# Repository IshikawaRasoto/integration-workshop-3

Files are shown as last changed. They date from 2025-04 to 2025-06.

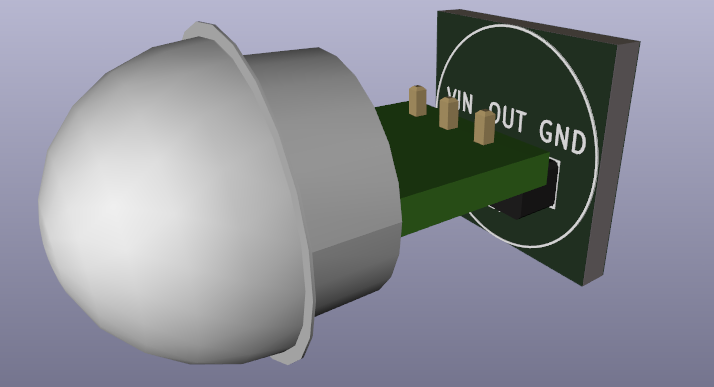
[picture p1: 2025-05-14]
electronics/kicad-5/documentation/am312_breakout/images/3d_view.png

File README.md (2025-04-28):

# Melody - Team #6

This repository contains all the development of project Melody for the course of Integration Workshop 3 in UTFPR-CT.

## Links 🔗

- [Project Overview](Melody.md) 🎵
- [Blog](Blog.md) :pencil2:
- [Schedule](https://docs.google.com/spreadsheets/d/16BKpbmt_EArwLnEZPB5oZgRN8s5iP5gV15BQ9Iq-7wM/edit?usp=sharing) :calendar:
- [Requirements](https://docs.google.com/spreadsheets/d/1uYC0gMrYfBv8li1KcnDvk5HJS1G1zU4XR2CenMT3GNY/edit?usp=sharing) ✔️
- [Risk Response Plans](https://docs.google.com/document/d/1Hm508SiW-laHHYEpOHIg4PhOxUlGecafFV3NObWFzSE/edit?usp=sharing)

## Members

- Rafael Rasoto 

- Nicolas Riuichi Oda 

- Augusto Rosa  

- Bruno Zenatti  

- Fernando Caetano  

- Rogério Slabiski Melo

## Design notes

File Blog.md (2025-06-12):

# Blog - Team #6

## Links 🔗

- [Project Review](./Melody.md) 🔍
  
- [Schedule](https://docs.google.com/spreadsheets/d/16BKpbmt_EArwLnEZPB5oZgRN8s5iP5gV15BQ9Iq-7wM/edit?usp=sharing) :calendar:
  
- [Requirements](https://docs.google.com/spreadsheets/d/1uYC0gMrYfBv8li1KcnDvk5HJS1G1zU4XR2CenMT3GNY/edit?usp=sharing) ✔️

- [Risk Analysis](./docs/ProjectRisks.md)

- [Risk Response Plans](https://docs.google.com/document/d/1Hm508SiW-laHHYEpOHIg4PhOxUlGecafFV3NObWFzSE/edit?usp=sharing)

- [Budget](./docs/Budget.md)
  
- [Software Diagramas](https://drive.google.com/drive/u/0/folders/1p14QvT_csh-KTkunY4fwNIppBQ_Pb9lO)

> [!NOTE]
> The more you scroll, older the posts will be.

## 11th week (06/06/2025 - 12/06/2025)

<a href="https://www.youtube.com/watch?v=N3duTqVcuXE">Link for Youtube Video</a>

> [!NOTE]
> The video is in portuguese because our project aims brazillians music teachers. However, there are English subtitles made by ourselves available on Youtube. Just enable them if you want :D

## 10th week (30/05/2025 - 05/06/2025)

https://github.com/user-attachments/assets/fdecbd82-0494-4a7e-a883-67b1e470544c

> [!NOTE]
> video doesn't work, here is the <a href="https://drive.google.com/file/d/1t6a54CX3tAcsUsGrWydN2q878OG4VS5w/view?usp=sharing">alternative link</a>
> or <a href="https://youtu.be/I3bCHIlh-NA"> another alternative link</a>

## 9th week (23/05/25 - 29/05/25)

Watch the video (https://youtu.be/XbjRi2Wo8Gw)

> [!NOTE]
> video doesn't work, here is the <a href="https://drive.google.com/file/d/1zL92fwCrnUkS4uXp7pSdOqfEj2-jlHWw/view?usp=sharing">alternative link</a>
> or <a href="https://youtu.be/XbjRi2Wo8Gw"> another alternative link</a>

### Weekly Progress Report

- **Worked Hours:** 41 hours  
- **Estimated Hours:** 57 hours 

#### Late Tasks:
- Implement gamified modes on the board
- Finish and Test electronics, on the universal board

**Total:** 10 hours

#### Advanced Tasks:
- Integrate configuration and mode selection via the web
- Assembly of the electronics in the mechanical system (Partial)
- Integrate software modules (Partial)

**Total:** 9 hours

### Balance of Hours:
- **-1 hours (Delayed)**

## 8th week (16/05/25 - 22/05/25)

Watch the video (https://youtu.be/CQ0k8XT7MOg)

> [!NOTE]
> video doesn't work, here is the <a href="https://drive.google.com/file/d/1eBVnDomfoXzMXdfsafBxS9mqTwlVErr4/view?usp=sharing">alternative link</a>
> or <a href="https://youtu.be/CQ0k8XT7MOg"> another alternative link</a>

### Weekly Progress Report

- **Worked Hours:** 50  
- **Estimated Hours:** 49  

#### Late Tasks:
- Acessibility Box adjusts
- PCB Test and Fine adjusts
- Plan note detection algorithm
- Communication between Raspberry and ESP
- Electronics integration 

**Total:** 12 hours

#### Advanced Tasks:
-  Creation Mode Logic
-  Gamified Modes Logic
-  Configuration and Mode selection via Web

**Total:** 10 hours

### Balance of Hours:
- **-2 hours (Delayed)**

### [Software Diagrams](https://drive.google.com/drive/u/0/folders/1p14QvT_csh-KTkunY4fwNIppBQ_Pb9lO)

## 7th week (10/05/25 - 15/05/25)

Watch the video (https://youtu.be/vphRbDHo6h4)

> [!NOTE]
> video doesn't work, here is the <a href="https://drive.google.com/file/d/1HU00oeIiyC617RvUnKEH0RWAW4GVyMLu/view?usp=sharing">alternative link</a>
> or <a href="https://youtu.be/vphRbDHo6h4"> another alternative link</a>

### Weekly Progress Report

- **Worked Hours:** 39  
- **Estimated Hours:** 51  

#### Late Tasks:
- Painting the table (musical sheet)  
- Universal board  
- Assembly of camera support and accessibility box  
- Technical drawing of the camera support  
**Total:** 24 hours

#### Advanced Tasks:
- Web interface  
- Implementation of the API between the Raspberry Pi and the web interface  
- Software flowchart  
**Total:** 15 hours

### Balance of Hours:
- **-9 hours (Delayed)**

### Considerations:
The machine responsible for laser cutting was inoperable this week due to a lack of distilled water. As a result, the camera support and accessibility box could not be completed. Painting the table is not a time-sensitive task, so it was postponed.

## 6th week (02/05/25 - 09/05/25)

https://github.com/user-attachments/assets/304e5314-0793-4925-b9ff-8a7de1e51dcb

> [!NOTE]
> video doesn't work, here is the <a href="https://drive.google.com/file/d/11PbM4jwNMG-VzaX_eZv_z7f3hip6sJxV/view?usp=drive_link">alternative link</a>

## 5th week (25/04/25 - 01/05/25)

https://drive.google.com/file/d/171ncvKebdySRcL43Z6NbSYb8b0LnE4rA/view?usp=sharing

> [!NOTE]
> video doesn't work, here is the <a href="https://drive.google.com/file/d/171ncvKebdySRcL43Z6NbSYb8b0LnE4rA/view?usp=sharing">alternative link</a>

This week we worked on modeling the mechanical part of Melody.

---

## 4th week (17/04/25 - 24/04/25)

https://github.com/user-attachments/assets/338b94e7-9b9c-4a17-a485-34453e6bfb96

> [!NOTE]
> If the video doesn't work, here is the <a href="https://drive.google.com/file/d/1DF5MuI8baSHS0etINNkh2YdKUNlma0PU/view?usp=sharing">alternative link</a>

This Week we worked on the planning of the project. As such, we:

- Defined the functional and non-functional requirements
- Defined the schedule of the project
- Propose the mitigation tasks for the top 10 priority risks of the project.

### Weekly Video

## 3rd week (10/04/25 - 16/04/25)

After selecting **Melody – MElodic LOgic for DYnamic learning** as our official project last week, our focus shifted towards planning. The main goals of the week included:

- Defining functional and non-functional requirements
- Structuring our project schedule
- Designing basic system diagrams
- Estimating a preliminary budget (B.O.M.)

---

### Weekly Video

https://github.com/user-attachments/assets/63315553-2686-44ac-ae38-a748cd99c074

- Project overview
- Requirements (hardware/software)
- Preliminary budget
- Task division and timeline

---

### Initial Schedule

Our starter project timeline here:  

📌 [Schedule Spreadsheet](https://docs.google.com/spreadsheets/d/1K51avpQig4mYJVM0eIMD89h_2f8xq5VL/edit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)

---

### Requirements

Detailed functional and non-functional requirements are available:  

📄 [Requirements Document](https://github.com/IshikawaRasoto/integration-workshop-3/blob/main/docs/Requirements.md)

---

### Risk Analysis

We started risk analysis this week to get a feedback from the professors:

:bomb: [Risk Analysis Preview ](https://docs.google.com/document/d/1Hm508SiW-laHHYEpOHIg4PhOxUlGecafFV3NObWFzSE/edit?usp=sharing)

---

### Bill of Materials (B.O.M.)

| Item | Price |
| --- | --- |
| USB Cam | R$ 100,00 |
| Raspberry Pi 4 B | R$ 300,00 |
| 3D Printing (2 PLA rolls) | R$ 150,00 |
| Plywood for board and camera mount | R$ 70,00 - R$ 200,00 |
| Simple Speaker | R$ 50,00 |
| 4x Servo Motor SG90 | R$ 50,00 |
| ESP32 | R$ 30,00 |
| Motor Vibracall | R$ 10,00 |
| 35x LEDs | R$ 20,00 |
| General Electronic Components | R$ 15,00 - R$ 75,00 |
| 2x Light Sources | R$ 30,00 |
| **Total** | **R$ 825,00 - R$ 1.015,00** |

---

### Weekly Meetings Recap

-Mon (14/04/25): Enhance the electronic part of the project, define the requirements of the project.

-Tue (15/04/25): Plan the project schedule, delegate responsabilities to the project members.

-Wen (16/04/25): Project diagrams, B.O.M,

---

## 2nd Week (03/04/25 - 09/04/25)

### Video of the week

https://github.com/user-attachments/assets/f6084483-0107-445c-9c83-dd5aefe4133e

> [!NOTE]
> If the video above doesn't work, here is the <a href="https://drive.google.com/file/d/1AGoXJWrNMAOkMldZtp4LrVlzvFSptPVR/view?usp=drive_link">link</a>

The feedback from the first week was the approval to continue develop our proposal A and also bring another idea. For this week, the team is supposed to deliver in more details both ideas.

### Week Proposals

- <a href="https://github.com/IshikawaRasoto/integration-workshop-3/blob/main/Melody.md">A. Melody</a> 🎵

- <a href="https://github.com/IshikawaRasoto/integration-workshop-3/blob/main/BajaValidation.md">B. Baja Validation </a> 🚙

## 1st Week (27/03/25 - 02/04/25)

As requested by the professors, the video below has a 10 minutes presentation about 3 proposals of projects to be developed during the course.

https://github.com/user-attachments/assets/d645352b-6435-41c7-a563-1140d3d22fad

> [!NOTE]
> If the video doens't work, here's the <a href="https://drive.google.com/file/d/1P5hyUBTmhP22Z2IB0QPu1I9AHRTu6y-r/view?usp=sharing">video link</a>

### A. Musicalization Project

The musicalization project has the objective to engage children in learning musical theory. Our proposal looks formward to the development of a table in which children can position pieces in a board which will represent the musical notes. The user will be able to control tempo, choose the instrument sound of which the system will play the notes, will have 2 or 3 octaves that can be chosen by the user. 

### B. Commercial Bafometer and Personal Bafometer

Project B seeks to solve a problema common in most of young adults lives. How to know if you are already sober after a session of drinking. Looking to solve this problem, our team is proposing the development of a system which will tell if a person is able to drive, and from this device, we'll be able to predict when a person will be able to drive by his metabolism, and also develop a system for places which sell drinks to ensure that, if someone is driving, he will only be able to take his car keys if he is sober and suited to drive.

### C. Parking Efficiency

Project C has the objective to solve a problem common in parking lots of concerts and shopping malls in events. The idea is to develop a smart system that will control the flow of vehicles entering and exiting the shopping mall in the most efficient way.

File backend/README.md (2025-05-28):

# Rodando o Servidor
- Crie o virtual enviroment
- Instale os pacotes do requirements.txt
- Na root do projeto (:~/integration-workshop-3$):
```
python3 main.py
```

# Documentação: Diretórios `core/` e `modes/`

Esta documentação detalha os componentes dos diretórios `core/` e `modes/` do projeto Melody, com foco no propósito de cada módulo e nas tarefas pendentes (TODOs).

---

### Diretório `core/`

O diretório `core/` contém os módulos centrais que formam a base da funcionalidade do projeto Melody.

#### 1. `core/hardware.py`

* **Propósito**: Este módulo é responsável por interagir com os componentes de hardware do projeto. Atualmente, ele define funções para controlar LEDs.
* **Funcionalidades**:
    * `turnOnLed(indexLed, color="GREEN")`: Acende um LED específico com uma cor definida (o padrão é verde).
    * `turnOffLed(indexLed)`: Apaga um LED específico.
* **🔴 TODOs/Pontos Pendentes**:
    * Implementar botões para chamar as respectivas funções de configuração (`set_volume`, `set_tempo`, `play/stop`).
    * Realmente acender e apagar os respectivos leds
    * Implementar um botão de emergência que reseta tudo.
    * Desenvolver a comunicação com o ESP32.
    * Implementar o controle do servo motor.
    * Implementar o controle do motor de vibração (vibracall).

---

#### 2. `core/noteDetection.py`

* **Propósito**: Este módulo é projetado para lidar com a detecção de notas musicais, presumivelmente através de uma câmera ou outro sensor.
* **Funcionalidades**:
    * `NoteDetection` (classe):
        * `__init__(self)`: Inicializa o detector, configurando `notes_detected` como `None` e `running` como `True`.
        * `detect_note_loop(self)`: Contém o loop principal para a detecção de notas.
        * `get_notes_detected(self)`: Retorna as notas detectadas.
        * `stop_note_detection_thread(self)`: Para a thread de detecção de notas.
* **🔴 TODOs/Pontos Pendentes**:
    * Implementar toda a lógica para detectar as notas dentro de `detect_note_loop`. A variável `self.notes_detected` é crucial e deve ser atualizada por esta lógica.

---

#### 3. `core/session.py`

* **Propósito**: Este módulo é **crucial** para o gerenciamento do estado global da aplicação. Ele mantém informações sobre o volume, tempo, estado de reprodução, página atual da interface, melodia selecionada, nota atual, status de acessibilidade e o índice da nota atual na melodia. Ele centraliza o estado para que diferentes partes do sistema (API, modos de operação) possam acessá-lo e modificá-lo de forma consistente. As funções `set_*` atualizam o estado e, em alguns casos, imprimem o novo valor no console para depuração. A função `as_dict()` é usada para transmitir o estado atual, provavelmente para a interface do usuário via WebSockets.
* **Funcionalidades**:
    * `PlayerState` (dataclass): Define a estrutura para armazenar o estado da sessão.
        * `volume`: Volume atual (0-100%).
        * `tempo`: Andamento atual (BPM).
        * `playing`: Booleano indicando se a música está tocando.
        * `page`: String que representa a página/estado atual da interface.
        * `melody`: Nome ou ID da melodia selecionada.
        * `note`: Nota atual dentro da melodia.
        * `accessibility`: Booleano indicando se o modo de acessibilidade está ativo.
        * `note_index`: Índice da nota atual na melodia.
    * `set_volume(value: int)`: Define o volume, limitado entre 0 e 100.
    * `set_tempo(bpm: int)`: Define o tempo, limitado entre 60 e 120 BPM.
    * `start_playback()`: Define `state.playing` como `True`.
    * `stop_playback()`: Define `state.playing` como `False`.
    * `select_melody(name: str)`: Seleciona uma melodia e define a nota inicial.
    * `set_page(name: str)`: Define a página/estado atual da interface.
    * `set_note(note: str)`: Define a nota atual.
    * `set_note_index(idx: int)`: Define o índice da nota atual.
    * `set_accessibility(flag: bool)`: Ativa/desativa o modo de acessibilidade.
    * `play_current_melody_note()`: Toca a nota atual da melodia selecionada, considerando sua duração.
    * `as_dict()`: Retorna o estado atual como um dicionário.
* **🔴 TODOs/Pontos Pendentes**:
    * Em `set_volume(value: int)`: Implementar a lógica para de fato **AUMENTAR O VOLUME NO ALTO-FALANTE**.
    * Em `play_current_melody_note()`: Adicionar a lógica para mais duas melodias além de "Ovelha Preta".

---

#### 4. `core/soundPlaying.py`

* **Propósito**: Este módulo é dedicado à geração e reprodução de sons de notas musicais. Ele usa `numpy` para gerar as ondas sonoras e `sounddevice` para reproduzi-las.
* **Funcionalidades**:
    * `sample_rate`: Taxa de amostragem para o áudio (44100 Hz).
    * `envelope(t, attack, decay, sustain_level, release)`: Define o envelope ADSR (Attack, Decay, Sustain, Release) para a nota, moldando sua amplitude ao longo do tempo.
    * `synthesize_note(frequency, duration)`: Gera a forma de onda para uma nota com uma determinada frequência e duração, aplicando o envelope.
    * `play_note_async(note, duration)`: Função assíncrona para tocar uma nota. Busca a frequência da nota no dicionário `note_freqs` (de `core.utils`), sintetiza a onda sonora (usando `asyncio.to_thread` para não bloquear o loop de eventos) e a reproduz usando `sounddevice`.
    * `run_sequence()`: Uma função de exemplo para tocar uma sequência de notas (escala de Dó).
* **🔴 TODOs/Pontos Pendentes**: Nenhum TODO explícito marcado no código, mas a funcionalidade depende das frequências de notas e melodias definidas em `core/utils.py`.

---

#### 5. `core/utils.py`

* **Propósito**: Este módulo serve como um utilitário para armazenar dados e constantes usados em outras partes do projeto, como definições de melodias e frequências de notas.
* **Funcionalidades**:
    * `OVELHA_PRETA`: Uma lista de tuplas representando as notas e suas durações para a melodia "Ovelha Preta".
    * `note_freqs`: Um dicionário mapeando nomes de notas (e seus acidentes como sustenido '#' ou bemol 'b') para suas frequências em Hertz.
* **🔴 TODOs/Pontos Pendentes**:
    * Adicionar o *hardcode* de mais melodias (sequência de notas com duração).
    * Completar o *hardcode* de notas, com suas frequências, etc. (embora `note_freqs` já pareça bastante completo).
    * Implementar o *hardcode* do mapeamento de notas (cor -> nota), que seria usado pela detecção de notas baseada em cores.

---

### Diretório `modes/`

O diretório `modes/` contém módulos que definem os diferentes modos de operação da aplicação Melody. Cada modo geralmente tem uma função `run_mode()` que é executada quando esse modo está ativo. O `ModeManager` em `backend/main.py` controla a transição entre esses modos com base no valor de `session.state.page`.

#### 1. `modes/creation.py`

* **Propósito**: Define o comportamento do "Modo de Criação". Neste modo, o sistema toca uma sequência de notas em loop, acendendo LEDs correspondentes a cada tempo/coluna no tabuleiro.
* **Funcionalidades**:
    * `run_mode()`: Loop principal do modo.
        * Verifica se `session.state.playing` é `True`.
        * Calcula o `columnIndex` (0-15) baseado nos `beats`.
        * Apaga o LED da coluna anterior e acende o LED da coluna atual.
        * Toca a nota correspondente à coluna atual da melodia `notes_and_durations`.
        * Incrementa `beats` e espera um tempo baseado no `session.state.tempo`.
    * `get_empty_board()`: Retorna uma representação de um tabuleiro vazio.
    * `get_duration_value(duration_string)`: Converte a string de duração ("quarter", "half", "whole") para um valor numérico.
* **🔴 TODOs/Pontos Pendentes**:
    * A variável `notes_and_durations` está atualmente usando `OVELHA_PRETA` como *mock*. Precisa ser atualizada para usar as notas realmente detectadas (presumivelmente do `noteDetection.py`) ou uma melodia que o usuário está criando.
    * No `run_mode()`, ao tocar a nota, deve usar a lista atualizada de notas, não uma fixa.

---

#### 2. `modes/hear.py`

* **Propósito**: Define o "Modo Escute a Nota". A intenção é que o sistema toque uma nota de uma melodia pré-carregada, e o usuário tente identificar e posicionar a nota correspondente no tabuleiro. O sistema então daria feedback.
* **Funcionalidades**:
    * `run_mode()`: Loop principal do modo.
        * Espera que `session.state.playing` seja `True` e que uma melodia (`session.state.melody`) esteja selecionada.
        * Contém placeholders para a lógica principal.
* **🔴 TODOs/Pontos Pendentes**:
    * Tocar a nota atual da melodia.
    * Esperar que o usuário posicione a nota correspondente.
    * Usar `noteDetection` para verificar se a nota posicionada corresponde à tocada.
    * Acender LED verde se correto e avançar o índice da nota.
    * Acender LED vermelho se incorreto.
    * Acender LED amarelo se nada for detectado.

---

#### 3. `modes/identify.py`

* **Propósito**: Define o "Modo Identifique a Nota". Neste modo, o sistema indica uma nota (presumivelmente mostrando-a na interface ou de outra forma visual), e o usuário deve posicioná-la no tabuleiro. O sistema verifica a correção.
* **Funcionalidades**:
    * `run_mode()`: Loop principal do modo.
        * Espera que `session.state.playing` seja `True` e que uma melodia (`session.state.melody`) esteja selecionada.
        * Contém placeholders para a lógica principal.
* **🔴 TODOs/Pontos Pendentes**:
    * Ler a nota atual da melodia usando `note_index`.
    * Usar `noteDetection` para ler a nota posicionada pelo usuário.
    * Comparar a nota detectada com a nota esperada.
    * Acender LED verde se correto e avançar o índice.
    * Acender LED vermelho se incorreto.
    * Acender LED amarelo se nada for detectado.

---

#### 4. `modes/idle.py`

* **Propósito**: Define o modo "Idle" ou "Home". Este é o estado padrão ou inicial da aplicação. Ele reseta a seleção de melodia e para a reprodução.
* **Funcionalidades**:
    * `run_mode()`:
        * Seleciona `None` para a melodia (`session.select_melody(None)`).
        * Para a reprodução (`session.stop_playback()`).
        * Entra em um loop enquanto `session.state.page` for "home".
        * Verifica se `session.state.accessibility` está ativo para executar a lógica correspondente.
* **🔴 TODOs/Pontos Pendentes**:
    * Se `session.state.accessibility` for `True`, implementar a lógica de comunicação com o ESP32 ("Turn on ESP32 Communication").

---

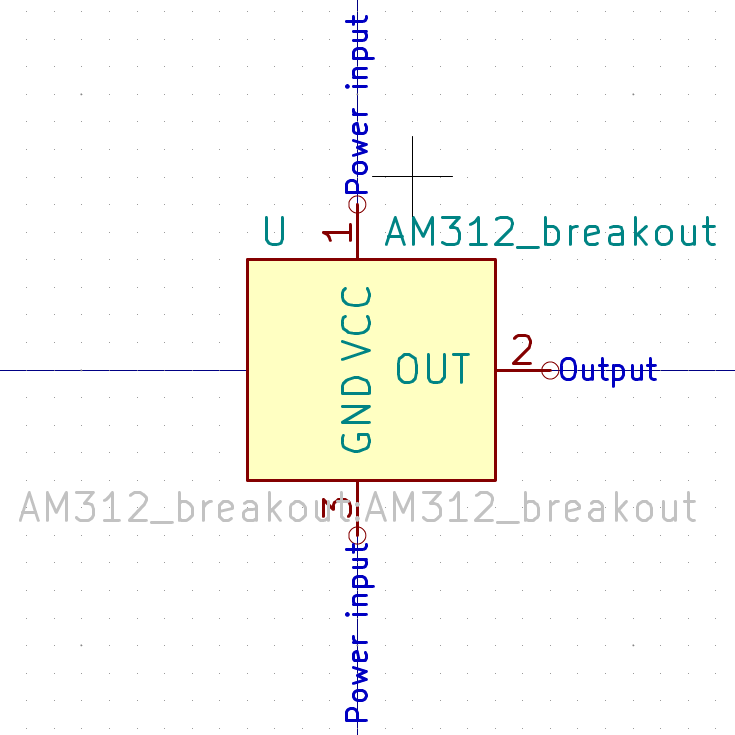
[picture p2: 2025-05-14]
electronics/kicad-5/documentation/aht10_breakout/images/symbol.png

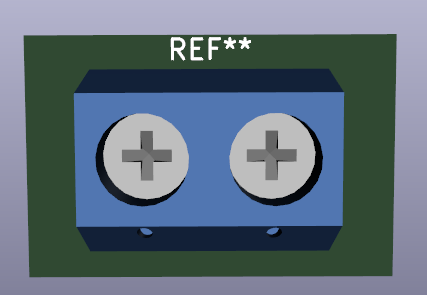
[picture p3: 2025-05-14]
electronics/kicad-5/documentation/kf301_5.0/images/3d_top.png

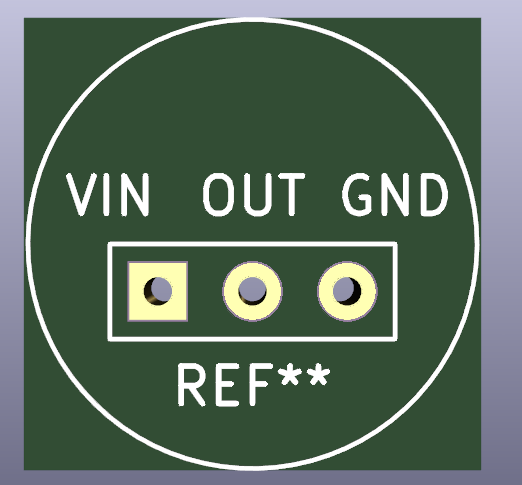
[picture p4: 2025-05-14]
electronics/kicad-5/documentation/am312_breakout/images/3d_silk.png

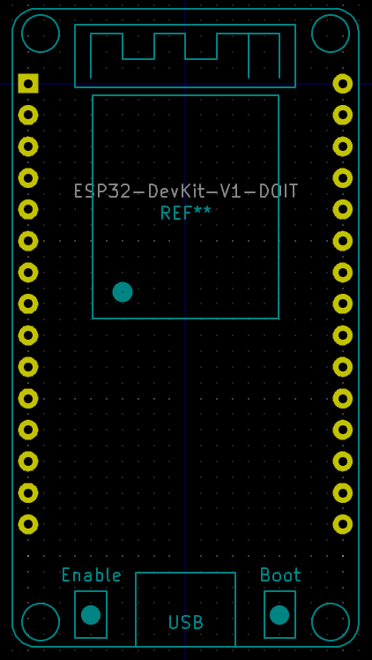
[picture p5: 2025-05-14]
electronics/kicad-5/documentation/esp32_devkit_v1_doit/images/footprint.png

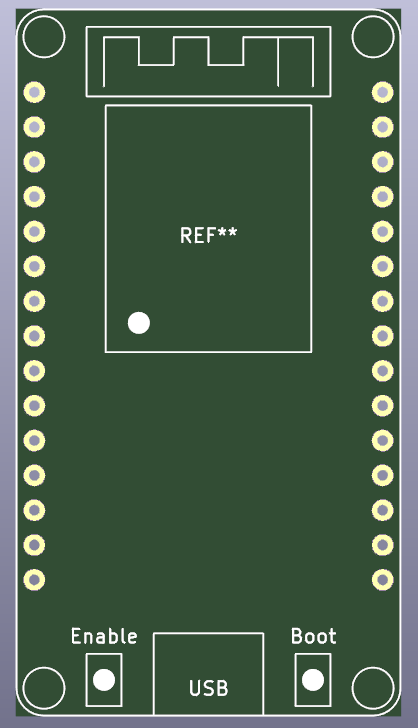
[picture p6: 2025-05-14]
electronics/kicad-5/documentation/esp32_devkit_v1_doit/images/3d_silk.png

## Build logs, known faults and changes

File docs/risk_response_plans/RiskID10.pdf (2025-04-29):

## Risk Response Plan Form

### Project: Melody

1st Step: Risk Identification
Name of the Risk:
Webcam wobbling

ID N°
10
Risk Description:
The webcam may shake or shift slightly due to an unstable or poorly mounted support structure, causing recognition errors or misalignment of visual input.

2nd Step: Risk Evaluation
Impact: 1(Very Low) 2(Low) 3(Average) X4(High) 5(Very High)

Explanation:
Camera wobbling can reduce image stability, leading to occasional recognition errors.

Probability:1(Very Low) X2(Low) 3(Average) 4(High) 5(Very High)

Explanation:
The camera mount is a physical structure that may initially be built from lightweight or imprecise materials

3rd Step: Risk Response Plan
Task, Who will do it, When it will be done! Strategies and Tasks that should be performed in order to reduce the “Impact”/“Probability” of this risk: Prevention Tasks:
Pin the webcam stand on the board. Include rubber pads or anti-slip elements at the base.

Mitigation Tasks:
Change the exposure time of the webcam to reduce motion blur.

Transfer* (use in last case, avoid if possible):

Acceptance Tasks (avoid at all costs!):

(* At Integration Workshop 3, it would not be possible to “transfer” the Risk outside of the team!)
Re-evaluated Impact (1~5): | 3 | Re-evaluated Probability (1-5): | 2
Elaborated by: Bruno | Date: 23/04/2025

Form based on Gasnier, 2000 (IMAN Editor), adjusted by Wille(UTFPR), translated to English by Fabro(UTFPR).

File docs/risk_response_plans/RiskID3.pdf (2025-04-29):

## Risk Response Plan Form

### Project: Melody

1st Step: Risk Identification
Name of the Risk:
Physical structure does not fit or align correctly (holes, webcam stand)

ID N°
3
Risk Description:
Misalignment or incorrect dimensions in the physical components (e.g., note holes, LED placement, webcam mount).

2nd Step: Risk Evaluation
Impact: 1(Very Low) 2(Low) X3(Average) 4(High) 5(Very High)

Explanation:
If the physical structure does not fit or align correctly, it may get harder to implement all requirements.

Probability:1(Very Low) 2(Low) 3(Average) X4(High) 5(Very High)

Explanation:
The team members are not used to projecting mechanical structures, it’s likely that the projects have some mistakes.

3rd Step: Risk Response Plan
Task, Who will do it, When it will be done! Strategies and Tasks that should be performed in order to reduce the “Impact”/“Probability” of this risk: Prevention Tasks:
Double-check all measurements and spacing (Double the time).
Mark drilling points carefully and test positioning before committing to permanent modifications. Involve more than one team member in reviewing and validating the design.

Mitigation Tasks:
Adjust or re-drill components if misalignment is minor and can be corrected.
Keep extra materials on hand for fast rework if needed, buy extra before working.

Transfer* (use in last case, avoid if possible):

Acceptance Tasks (avoid at all costs!):

(* At Integration Workshop 3, it would not be possible to “transfer” the Risk outside of the team!)
Re-evaluated Impact (1~5): 3 | Re-evaluated Probability (1-5): 2
Elaborated by: Bruno | Date: 23/04/2025

Form based on Gasnier, 2000 (IMAN Editor), adjusted by Wille(UTFPR), translated to English by Fabro(UTFPR).

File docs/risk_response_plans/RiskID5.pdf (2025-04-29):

## Risk Response Plan Form

### Project: Melody

1st Step: Risk Identification
Name of the Risk:
Problems with Raspberry Pi performance (lag or overheating)

ID N°
5
Risk Description:
If the board doesn’t accomplish what is expected

2nd Step: Risk Evaluation
Impact: 1(Very Low) 2(Low) X3(Average) 4(High) 5(Very High)

Explanation:
This might impact on the child’s interest about the project, the system might experience delays in processing or audio playback. It would just reduce responsiveness or cause minor interruptions.

Probability:1(Very Low) 2(Low) X3(Average) 4(High) 5(Very High)

Explanation:
The raspberry pi chosen for the project is quite good, but it is still a possibility.

3rd Step: Risk Response Plan
Task, Who will do it, When it will be done! Strategies and Tasks that should be performed in order to reduce the “Impact”/“Probability” of this risk: Prevention Tasks:
Limit camera frame rate and resolution and monitoring system resource usage during development.

Mitigation Tasks:
Include a reboot/restart mechanism in case the system becomes unresponsive.

Transfer* (use in last case, avoid if possible):

Acceptance Tasks (avoid at all costs!):

(* At Integration Workshop 3, it would not be possible to “transfer” the Risk outside of the team!)
Re-evaluated Impact (1~5): 2 | Re-evaluated Probability (1-5):2
Elaborated by: Bruno | Date: 23/04/2025

Form based on Gasnier, 2000 (IMAN Editor), adjusted by Wille(UTFPR), translated to English by Fabro(UTFPR).

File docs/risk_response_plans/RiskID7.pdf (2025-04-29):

## Risk Response Plan Form

### Project: Melody

1st Step: Risk Identification
Name of the Risk:
Power supply is unstable or insufficient

ID N°
7
Risk Description:
If the power supply doesn’t supply enough power to the system or the power source has fluctuations

2nd Step: Risk Evaluation
Impact: 1(Very Low) 2(Low) X 3(Average) 4(High) 5(Very High)

Explanation:
There might not be enough power to actuate the motors and power the raspberry and ESP32, the motors might end up causing instabilities in the power for the electronics

Probability: 1(Very Low) 2(Low) X 3(Average) 4(High) 5(Very High)

Explanation:
The power load calculated might no be enough to the whole system, the effect of the motors in the system might be more than expected

3rd Step: Risk Response Plan
| Task, Who will do it, When it will be done!
Strategies and Tasks that should be performed in order to reduce the “Impact”/“Probability” of this risk: Prevention Tasks:
Use a power supply with enough power to power the system at max load.

Mitigation Tasks:
Separate the power supply in two circuits, one for the raspberry and ESP32 and other for the power electronics.

Transfer* (use in last case, avoid if possible):

Acceptance Tasks (avoid at all costs!):

(* At Integration Workshop 3, it would not be possible to “transfer” the Risk outside of the team!)
Re-evaluated Impact (1~5): 2 | Re-evaluated Probability (1-5): 2
Elaborated by: Fernando | Date: 23/04/2025

Form based on Gasnier, 2000 (IMAN Editor), adjusted by Wille(UTFPR), translated to English by Fabro(UTFPR).

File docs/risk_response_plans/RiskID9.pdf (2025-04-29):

## Risk Response Plan Form

### Project: Melody

1st Step: Risk Identification
Name of the Risk:
Hardware component burns out

ID N°
9
Risk Description:
Hardware components like the might burn out from misuse

2nd Step: Risk Evaluation
Impact: 1(Very Low) 2(Low) 3(Average) X 4(High) 5(Very High)

Explanation:
Some components like the LEDs or the motors might impact the functionality but the rest of the system would still be functional. Failure of the raspberry would impact the whole system.

Probability: 1(Very Low) X 2(Low) 3(Average) 4(High) 5(Very High)

Explanation:
The members of the team have experience handling the components used in the system, unlikely to happen.

3rd Step: Risk Response Plan
| Task, Who will do it, When it will be done!
Strategies and Tasks that should be performed in order to reduce the “Impact”/“Probability” of this risk: Prevention Tasks:
Test the connections and subcircuits before assembling the whole circuit.

Mitigation Tasks:
Having a spare Raspberry 3B, 4 Servo motors, a vibration motor and a ESP32.

Transfer* (use in last case, avoid if possible):

Acceptance Tasks (avoid at all costs!):

(* At Integration Workshop 3, it would not be possible to “transfer” the Risk outside of the team!)
Re-evaluated Impact (1~5): 2 | Re-evaluated Probability (1-5): 2
Elaborated by: Fernando | Date: 23/04/2025

Form based on Gasnier, 2000 (IMAN Editor), adjusted by Wille(UTFPR), translated to English by Fabro(UTFPR).

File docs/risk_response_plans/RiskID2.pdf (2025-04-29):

## Risk Response Plan Form

### Project: Melody

1st Step: Risk Identification
Name of the Risk:
Team member leaving the project

ID N°
2
Risk Description:
One or two members leave the project

2nd Step: Risk Evaluation
Impact: 1(Very Low) 2(Low) 3(Average) 4(High) X 5(Very High)

Explanation:

Most tasks are assigned to specific individuals. If someone leaves, their responsibilities must be reallocated, which can significantly impact progress.

Probability:1(Very Low) 2(Low) X3(Average) 4(High) 5(Very High)

Explanation:
Unexpected events might occur, and team members already have tight schedules.

3rd Step: Risk Response Plan
Task, Who will do it, When it will be done! Strategies and Tasks that should be performed in order to reduce the “Impact”/“Probability” of this risk: Prevention Tasks:
Each task should have at least one assistant who is also the backup. Every assistant asks the responsible one if he needs help every week.

Mitigation Tasks:
Reassign the departing member’s responsibilities to their designated assistant.
Remove the requirements marked as "Risk Removable" on the Requirements according to the number of members leaving.
Reassign the ownership of these requirements to support the backup for the departing member.

Transfer* (use in last case, avoid if possible):

Acceptance Tasks (avoid at all costs!):

(* At Integration Workshop 3, it would not be possible to “transfer” the Risk outside of the team!)
Re-evaluated Impact (1~5):2 | Re-evaluated Probability (1-5):2
Elaborated by: Bruno | Date: 23/04/2025

Form based on Gasnier, 2000 (IMAN Editor), adjusted by Wille(UTFPR), translated to English by Fabro(UTFPR).

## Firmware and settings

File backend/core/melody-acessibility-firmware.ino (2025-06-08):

#include <ESP32Servo.h>

#define SERVO_1_PIN 2
#define SERVO_2_PIN 4
#define SERVO_3_PIN 16
#define SERVO_4_PIN 17
#define VIBRACALL_PIN 19

#define BUFFER_SIZE 32

Servo servo1;
Servo servo2;
Servo servo3;
Servo servo4;

// Função para definir o duty cycle de um servo específico
void setServoDuty(int servoNum, int duty)
{
    // Garante que o duty cycle está dentro dos limites
    duty = constrain(duty, 0, 100);

    // Mapeia de 0-100% para o valor de pulso do servo (500-2400us é um range comum)
    int pulseWidth = map(duty, 0, 100, 500, 2400);

    // Aplica ao servo correto
    switch (servoNum)
    {
    case 1:
        servo1.writeMicroseconds(pulseWidth);
        break;
    case 2:
        servo2.writeMicroseconds(pulseWidth);
        break;
    case 3:
        servo3.writeMicroseconds(pulseWidth);
        break;
    case 4:
        servo4.writeMicroseconds(pulseWidth);
        break;
    }
}

void setup()
{
    pinMode(VIBRACALL_PIN, OUTPUT);
    Serial.begin(115200);
    servo1.attach(SERVO_1_PIN);
    servo2.attach(SERVO_2_PIN);
    servo3.attach(SERVO_3_PIN);
    servo4.attach(SERVO_4_PIN);

    // Inicia os motores na posicao default
    setServoDuty(SERVO_1_PIN, 0);
    setServoDuty(SERVO_2_PIN, 0);
    setServoDuty(SERVO_3_PIN, 0);
    setServoDuty(SERVO_4_PIN, 0);
}

void loop()
{
    if(Serial.available() > 0){
        char command =Serial.read();
        switch(command){
            case '1':
                setServoDuty(4,50);
                setServoDuty(1,0);
                digitalWrite(VIBRACALL_PIN, HIGH);
                delay(500);
                digitalWrite(VIBRACALL_PIN, LOW);
                break;
            case '2':
                setServoDuty(1,50);
                setServoDuty(2,0);
                digitalWrite(VIBRACALL_PIN, HIGH);
                delay(500);
                digitalWrite(VIBRACALL_PIN, LOW);
                break;
            case '3':
                setServoDuty(2,50);
                setServoDuty(3,0);
                digitalWrite(VIBRACALL_PIN, HIGH);
                delay(500);
                digitalWrite(VIBRACALL_PIN, LOW);
                break;
            case '4':
                setServoDuty(3,50);
                setServoDuty(4,0);
                digitalWrite(VIBRACALL_PIN, HIGH);
                delay(500);
                digitalWrite(VIBRACALL_PIN, LOW);
                break;
            case '5':
                setServoDuty(1,50);
                setServoDuty(2,50);
                setServoDuty(3,50);
                setServoDuty(4,50);
                break;
            case '6':
                digitalWrite(VIBRACALL_PIN,HIGH);
                delay(500);
                digitalWrite(VIBRACALL_PIN,LOW);
                break;
            case '7':
                digitalWrite(VIBRACALL_PIN,HIGH);
                delay(500);
                digitalWrite(VIBRACALL_PIN,LOW);
                delay(50);       
                digitalWrite(VIBRACALL_PIN,HIGH);
                delay(500);
                digitalWrite(VIBRACALL_PIN,LOW);
                break;
        }
    }
}                 

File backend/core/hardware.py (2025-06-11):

import RPi.GPIO as gpio
import time
import asyncio
from core import session
from api import manager

# Pinos de saida dos DEMUX
GREEN_OUTPUT_PIN = 0
RED_OUTPUT_PIN = 5

# Pinos de endereçamento (4 bits: A0, A1, A2, A3)
GREEN_ADDRESS_PINS = [22, 10, 9, 11]
RED_ADDRESS_PINS = [6, 13, 19, 26]

# Mapeamento de LED para pino do DEMUX
RED_MAP =   [ 0, 8, 4,12,  1, 9, 5, 13,  2, 10,  6, 14,  3, 11,  7, 15]
GREEN_MAP = [13, 5, 9, 1, 12, 4, 8,  0, 15,  7, 11,  3, 14,  6, 10,  2]

BUTTON_GPIO_PINS = [21, 20, 16, 12, 1, 7, 8]
SYSTEM_ON = True 

main_event_loop = None
api_manager = None

def set_main_loop_and_manager(loop, manager_instance):
    """
    Called by main.py to provide the asyncio loop and API manager.
    """
    global main_event_loop, api_manager
    main_event_loop = loop
    api_manager = manager_instance
    print("[Hardware] Main event loop and API manager have been set.")

# Função para selecionar um canal (0 a 15)
def set_address(channel):
    if channel < 0 or channel > 15:
        print("Canal inválido! Use 0-15.")
        return
    
    # Converter o número do canal para binário (4 bits)
    red_bits = [int(bit) for bit in format(RED_MAP[channel], '04b')]
    green_bits = [int(bit) for bit in format(GREEN_MAP[channel], '04b')]

    # Aplicar os bits aos pinos de endereço
    for i, pin in enumerate(RED_ADDRESS_PINS):
        gpio.output(pin, red_bits[i])

    for i, pin in enumerate(GREEN_ADDRESS_PINS):
        gpio.output(pin, green_bits[i])

def turnOnLed(indexLed, color="GREEN"):
    print(f"Turning on led: {indexLed}. Color: {color}")
    set_address(indexLed)
    if color.upper() == "GREEN":
        gpio.output(GREEN_OUTPUT_PIN, gpio.LOW)
        gpio.output(RED_OUTPUT_PIN, gpio.HIGH)
    elif color.upper() == "RED":
        gpio.output(RED_OUTPUT_PIN, gpio.LOW)
        gpio.output(GREEN_OUTPUT_PIN, gpio.HIGH)
    elif color.upper() == "YELLOW":
        gpio.output(RED_OUTPUT_PIN, gpio.HIGH)
        gpio.output(GREEN_OUTPUT_PIN, gpio.HIGH)
    else: # Off for unknown colors or "None"
        gpio.output(RED_OUTPUT_PIN, gpio.HIGH)
        gpio.output(GREEN_OUTPUT_PIN, gpio.HIGH)


def turnOffLed(indexLed):
    print(f"Turning off led: {indexLed}")
    # Setting both to HIGH effectively disables the output of the demux
    gpio.output(RED_OUTPUT_PIN, gpio.HIGH)
    gpio.output(GREEN_OUTPUT_PIN, gpio.HIGH)

def turnOffAllLeds():
    print(f"Turning off all leds")
    gpio.output(RED_OUTPUT_PIN, gpio.HIGH)
    gpio.output(GREEN_OUTPUT_PIN, gpio.HIGH)

def emergency_off_actions():
    #TODO testar
    global SYSTEM_ON
    SYSTEM_ON = False
    print("System OFF ")
    turnOffAllLeds()
    #os.func("sudo reboot")

def system_on_actions():
    global SYSTEM_ON
    SYSTEM_ON = True
    #Set to default
    reset_melody()
    print("System ON")

def reset_melody():
    session.set_page("home") 
    session.set_volume(50) 
    session.set_tempo(60)  
    session.set_accessibility(False)
    session.set_note(None)
    session.set_note_index(0)
    session.select_melody(None)

def button_callback(pin):
    global SYSTEM_ON, main_event_loop, api_manager
    try:
        button_index = BUTTON_GPIO_PINS.index(pin)
    except ValueError:
        print(f"Unknown pin {pin} pressed.")
        return

    if button_index == 6: # Turn On/Off button
        
        emergency_off_actions()

        if api_manager and main_event_loop and main_event_loop.is_running():
            asyncio.run_coroutine_threadsafe(api_manager.broadcast_state(), main_event_loop)
            print("[Hardware] System ON/OFF state broadcast scheduled.")
        
        return

    if not SYSTEM_ON:
        print("System is OFF. Press Button 7 to turn ON.")
        return

    action_taken = False
    if button_index == 0: # Play
        session.start_playback()
        print("Playback started via hardware button.")
        action_taken = True
    elif button_index == 1: # Stop
        session.stop_playback()
        print("Playback stopped via hardware button.")
        action_taken = True
    elif button_index == 2: # Volume +
        current_volume = session.state.volume
        session.set_volume(min(100, current_volume + 5))
        print(f"Volume increased to {session.state.volume}% via hardware button.")
        action_taken = True
    elif button_index == 3: # Volume -
        current_volume = session.state.volume
        session.set_volume(max(0, current_volume - 5))
        print(f"Volume decreased to {session.state.volume}% via hardware button.")
        action_taken = True
    elif button_index == 4: # Tempo +
        current_tempo = session.state.tempo
        session.set_tempo(min(120, current_tempo + 30))
        print(f"Tempo increased to {session.state.tempo} BPM via hardware button.")
        action_taken = True
    elif button_index == 5: # Tempo -
        current_tempo = session.state.tempo
        session.set_tempo(max(60, current_tempo - 30))
        print(f"Tempo decreased to {session.state.tempo} BPM via hardware button.")
        action_taken = True

    if action_taken:
        if api_manager and main_event_loop and main_event_loop.is_running():
            future = asyncio.run_coroutine_threadsafe(api_manager.broadcast_state(), main_event_loop)
            try:
                future.result(timeout=1) # Wait for 1 second
                print("[Hardware] Broadcast state successfully scheduled and completed from button callback.")
            except asyncio.TimeoutError:
                print("[Hardware] Warning: Broadcast state scheduling timed out.")
            except Exception as e:
                print(f"[Hardware] Error during broadcast_state: {e}")
        elif not (api_manager and main_event_loop):
            print("[Hardware] Error: API manager or event loop not set. Cannot broadcast.")
        elif not main_event_loop.is_running():
            print("[Hardware] Error: Event loop not running. Cannot broadcast.")


def setup():
    gpio.setmode(gpio.BCM)
    gpio.setwarnings(False)

    # Configurar pinos de LED
    gpio.setup(RED_OUTPUT_PIN, gpio.OUT)
    gpio.setup(GREEN_OUTPUT_PIN, gpio.OUT)
    gpio.output(RED_OUTPUT_PIN, gpio.HIGH) # Desligado
    gpio.output(GREEN_OUTPUT_PIN, gpio.HIGH) # Desligado

    for pin in RED_ADDRESS_PINS + GREEN_ADDRESS_PINS:
        gpio.setup(pin, gpio.OUT)
        gpio.output(pin, gpio.LOW)

    # Configurar pinos de botão
    for pin in BUTTON_GPIO_PINS:
        gpio.setup(pin, gpio.IN, pull_up_down=gpio.PUD_UP)
        gpio.add_event_detect(pin, gpio.FALLING, callback=button_callback, bouncetime=300)

try:
    setup()
    print("Hardware buttons initialized.")
except RuntimeError:
    print("Could not setup GPIO. RPi.GPIO error.")
except Exception as e:
    print(f"An error occurred during hardware setup: {e}")

def cleanup_gpio():
    print("Cleaning up GPIO...")
    gpio.cleanup()
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

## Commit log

2025-04-10 📝 Update Melody.md
2025-04-10 :memo: Update Melody.md - BOM
2025-05-09 add electronics
    [accessibility_module.kicad_pcb, accessibility_module.kicad_sch, melody.kicad_pcb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]
2025-05-14 change IC 74->40 + shared power supply for processors + PCB
    [accessibility_module.kicad_pcb, accessibility_module.kicad_sch, melody.kicad_pcb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]
2025-05-14 communication front-back almost done, missing page, missing improvements
    [api.py, session.py]
2025-05-14 added TODOs, missing testing backend->front
    [session.py]
2025-05-18 Melody schematic update
    [melody.kicad_sch]
2025-05-18 creation mode logic finished, missing playing and detection only
    [hardware.py]
2025-05-21 added the note detection thread
2025-05-21 added hear note button, added custom note
2025-05-28 Atualização esquemático eletrônico
    [accessibility_module.kicad_sch, melody.kicad_sch]
2025-05-28 added the correct notes for the musics in utils.py
    [utils.py]
2025-05-30 started buttons interruptions
2025-05-31 detection thread salvando fotos
2025-05-31 button updating web
2025-05-31 detection thread
2025-05-31 buttons instances
2025-05-31 buttons gpio
2025-05-31 calibration test
2025-05-31 working with fixed calibration
    [detectionThread.py, main.py, utils.py]
2025-05-31 limitando buffer de video pra 1 frame
2025-06-08 leds and buttons integrated
2025-06-08 added esp32 firmware
2025-06-08 fixed leds map
2025-06-12 add led module schematics
    [led_module.kicad_pcb, led_module.kicad_sch]
